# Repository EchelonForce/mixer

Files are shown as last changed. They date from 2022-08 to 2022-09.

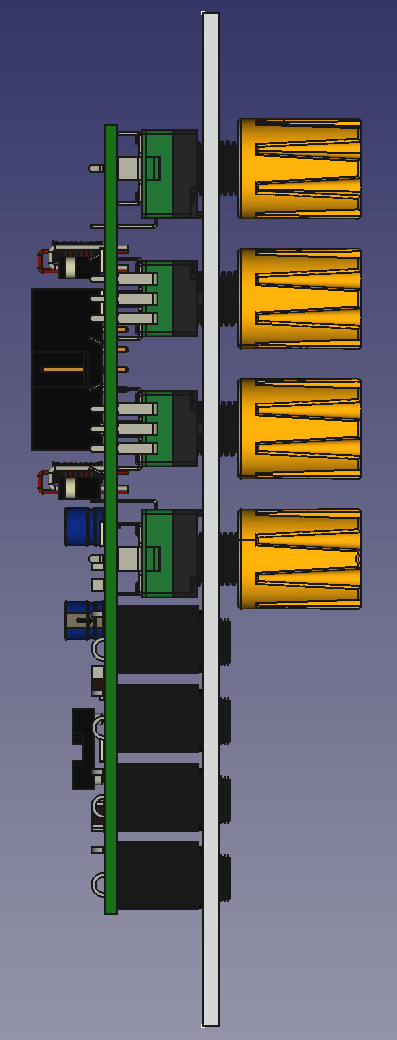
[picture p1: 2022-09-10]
front_panel_v1/render3.png

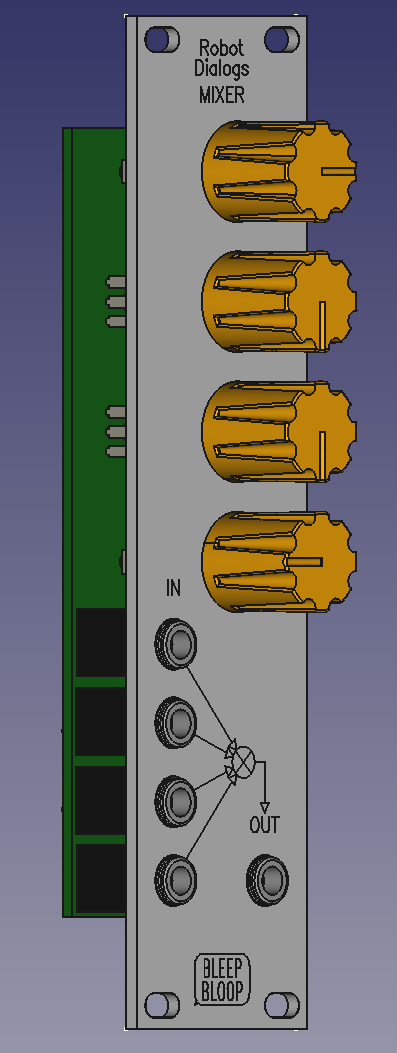
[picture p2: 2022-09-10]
front_panel_v1/render2.png

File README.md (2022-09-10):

# Eurorack Mixer Module

This the KiCAD design of a Eurorack mixer module with 4 inputs.

Full writeup here: https://www.robotdialogs.com/2022/09/eurorack-41-mixer-module.html

This work is licensed under a Creative Commons Attribution-NonCommercial-ShareAlike 4.0 International License. https://creativecommons.org/licenses/by-nc-sa/4.0/

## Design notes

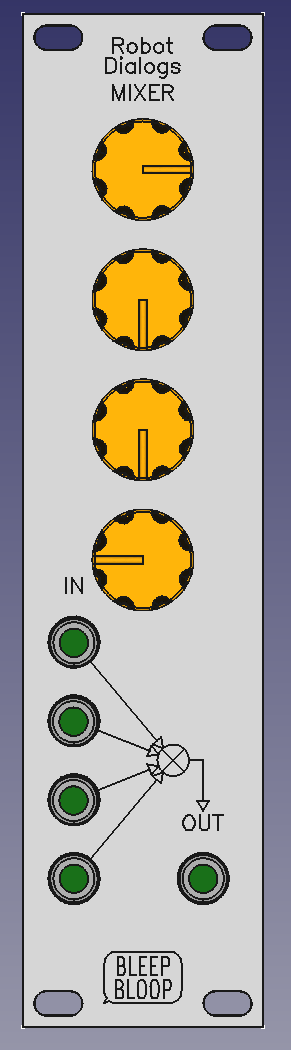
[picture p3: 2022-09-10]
front_panel_v1/render1.png

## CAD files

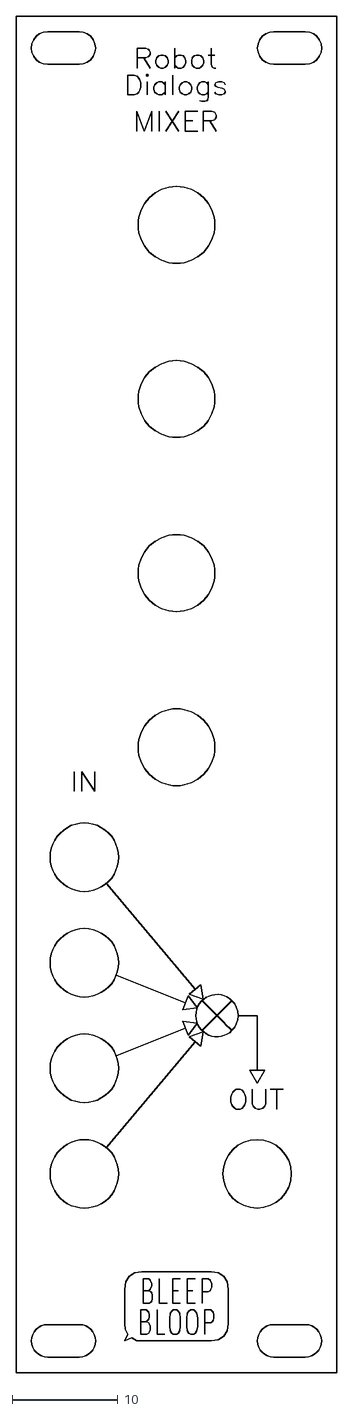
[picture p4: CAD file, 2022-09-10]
front_panel_v1/mixer_front_panel_v1_engraving.dxf
30.4 x 128.4

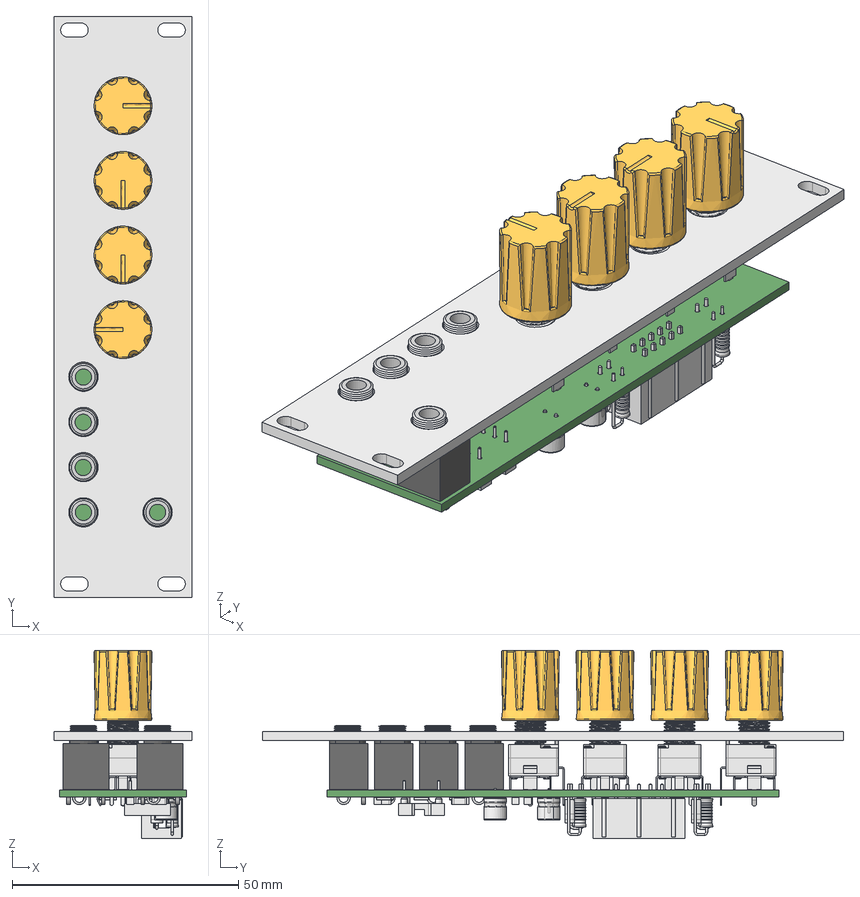
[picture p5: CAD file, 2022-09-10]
front_panel_v1/mixer_front_panel_v1.FCStd
30.5 x 128.5 x 41.6 mm
_autosave-mixer_v1 PCB

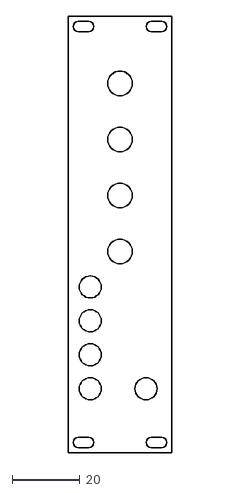
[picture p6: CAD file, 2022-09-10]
front_panel_v1/mixer_front_panel_v1_no_engraving.dxf
30.5 x 128.5

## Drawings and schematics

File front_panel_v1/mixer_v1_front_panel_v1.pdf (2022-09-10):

1

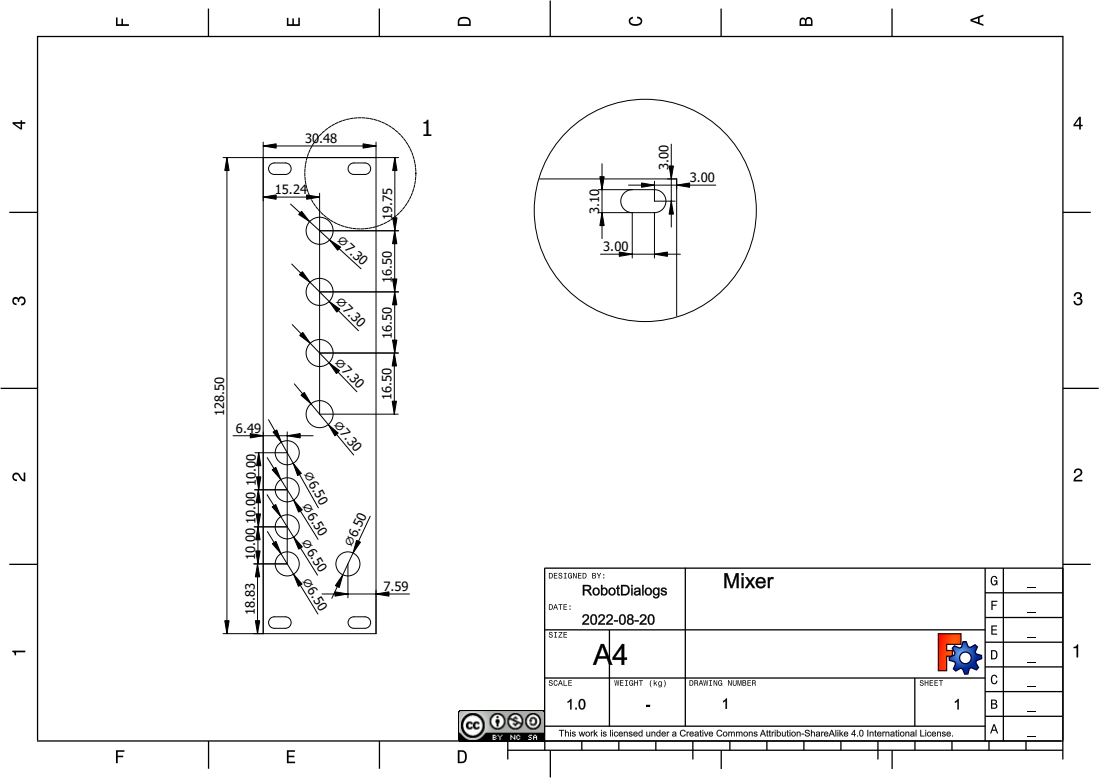
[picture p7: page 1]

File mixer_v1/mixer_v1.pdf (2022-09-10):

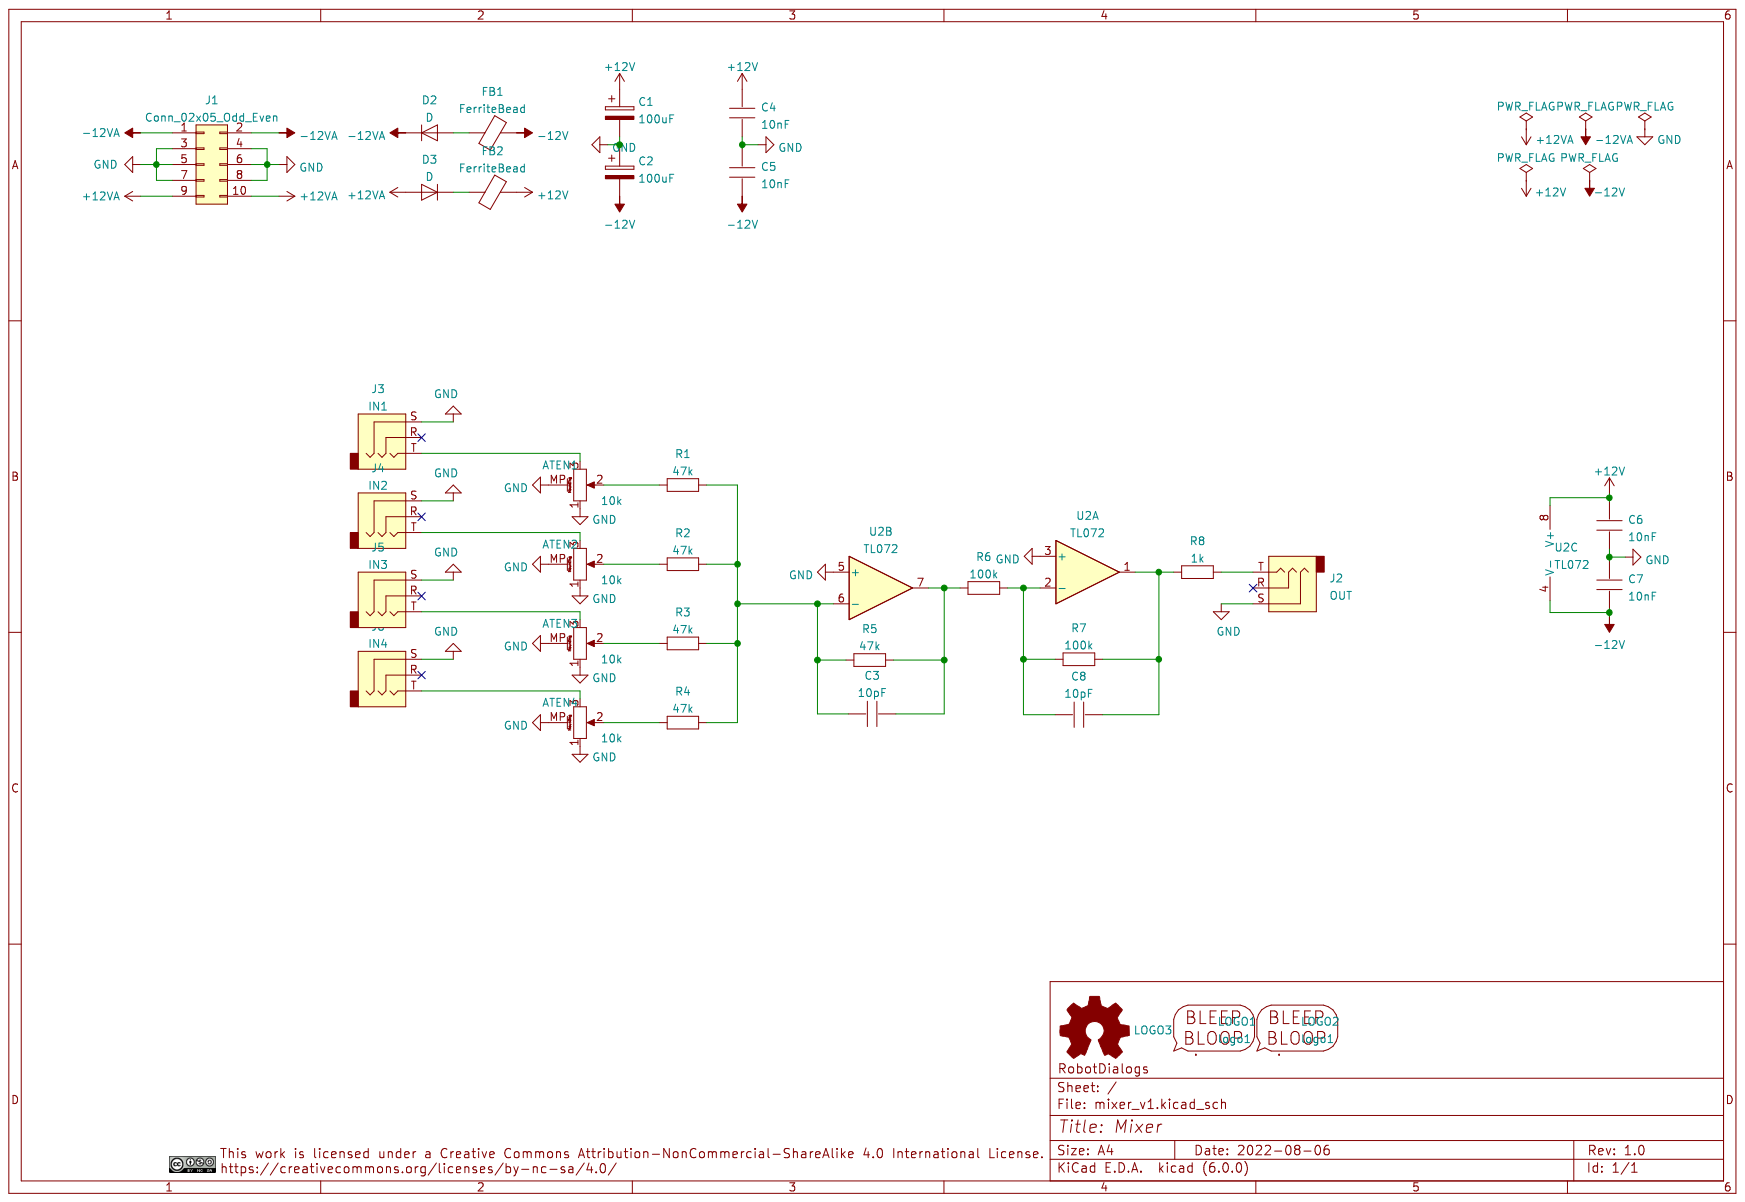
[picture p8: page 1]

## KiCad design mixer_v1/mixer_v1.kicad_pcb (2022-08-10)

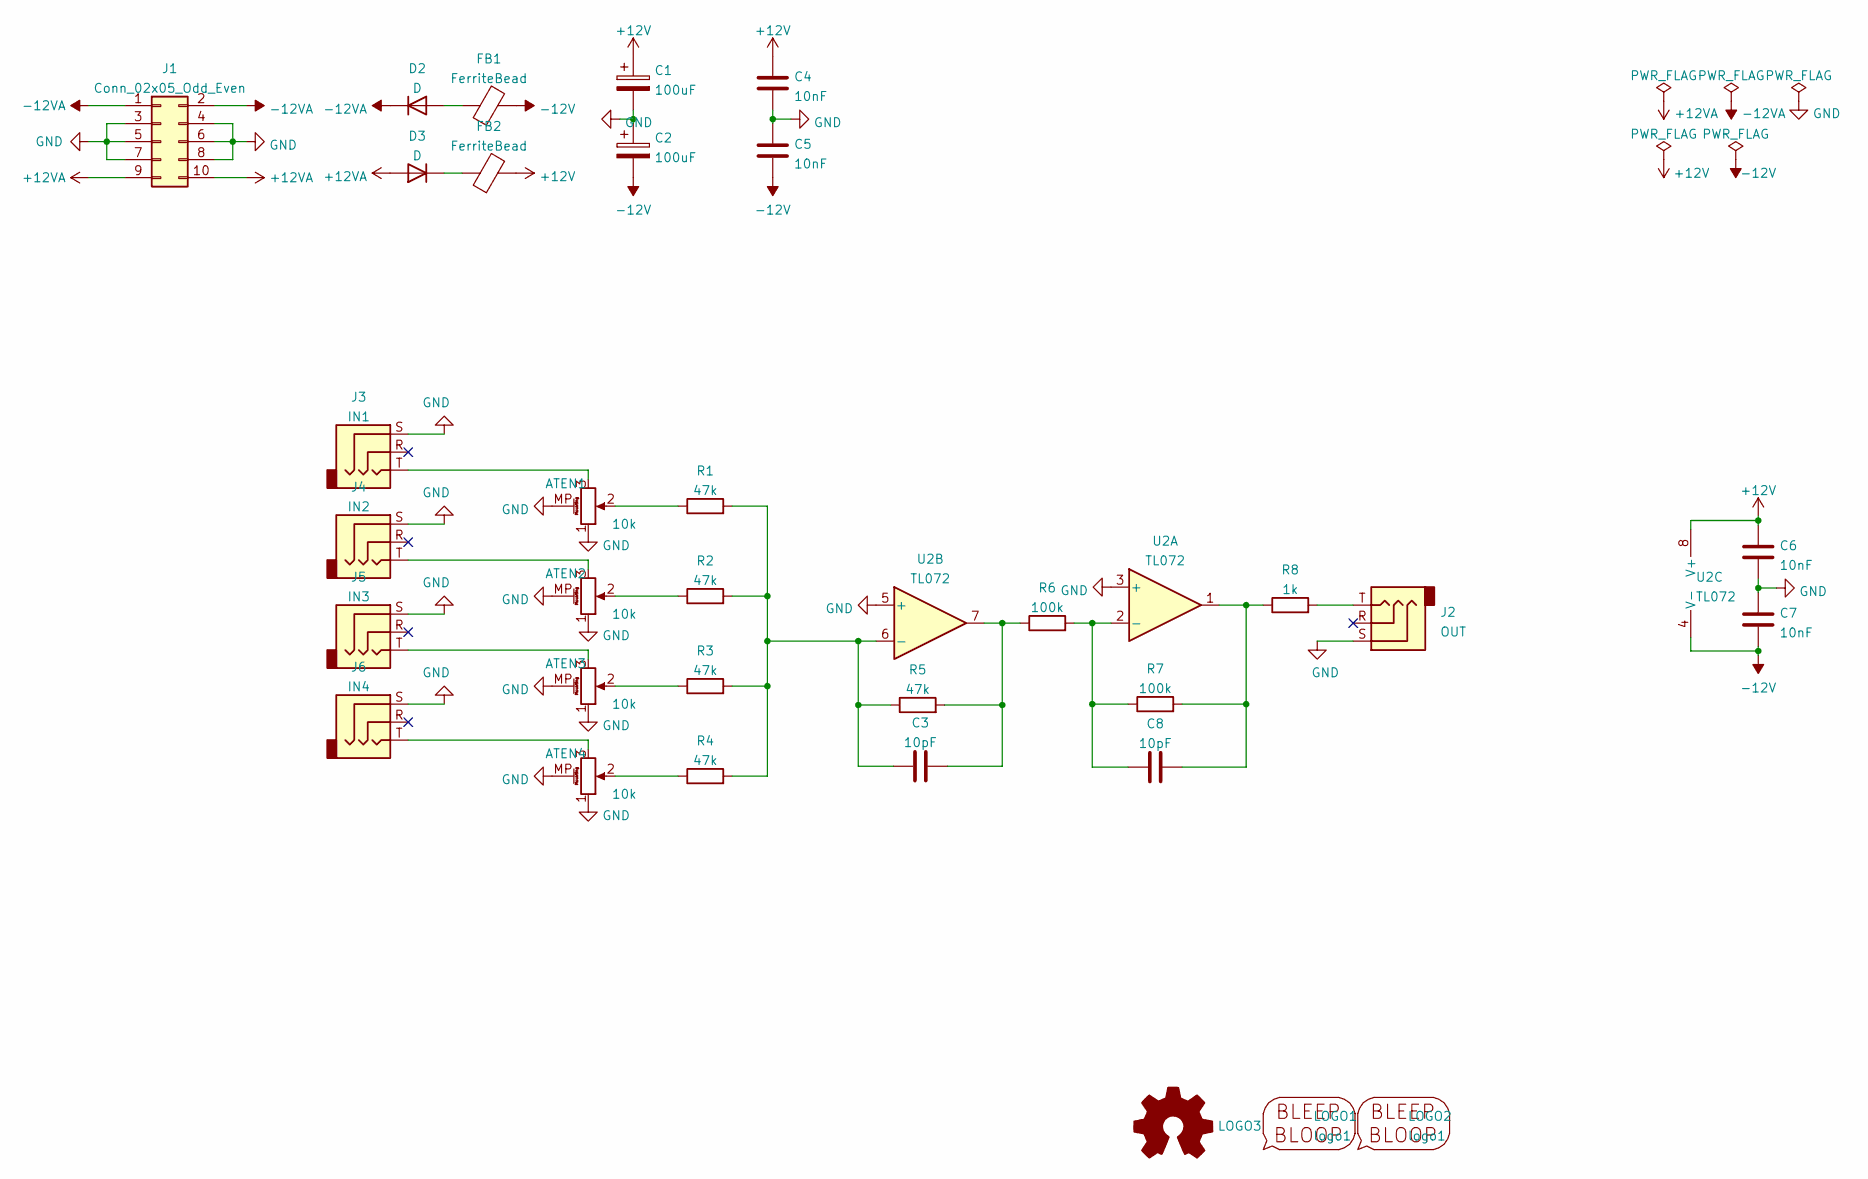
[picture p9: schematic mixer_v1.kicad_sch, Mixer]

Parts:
ATEN1, ATEN2, ATEN3, ATEN4: 10k; Potentiometer_Alpha_RD901F-40-00D_Single_Vertical_w_3d
C1, C2: 100uF; CP_Radial_D5.0mm_P2.50mm
C3, C8: 10pF; C_1206_3216Metric_Pad1.33x1.80mm_HandSolder
C4, C5, C6, C7: 10nF; C_1206_3216Metric_Pad1.33x1.80mm_HandSolder
D2, D3: D; D_A-405_P2.54mm_Vertical_KathodeUp
FB1, FB2: FerriteBead; L_Axial_L6.6mm_D2.7mm_P2.54mm_Vertical_Vishay_IM-2
J1: Conn_02x05_Odd_Even; IDC-Header_2x05_P2.54mm_Vertical
J2: OUT; Jack_3.5mm_MJ-355W_Vertical
J3: IN1; Jack_3.5mm_MJ-355W_Vertical
J4: IN2; Jack_3.5mm_MJ-355W_Vertical
J5: IN3; Jack_3.5mm_MJ-355W_Vertical
J6: IN4; Jack_3.5mm_MJ-355W_Vertical
LOGO1: logo1; Logo1
LOGO2: logo1; Logo2
LOGO3: Logo_Open_Hardware_Small; OSHW-Symbol_6.7x6mm_SilkScreen
R1, R2, R3, R4, R5: 47k; R_1206_3216Metric_Pad1.30x1.75mm_HandSolder
R6, R7: 100k; R_1206_3216Metric_Pad1.30x1.75mm_HandSolder
R8: 1k; R_1206_3216Metric_Pad1.30x1.75mm_HandSolder
U2: TL072; DIP-8_W7.62mm_Socket_LongPads

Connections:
+12V: C1.1, C4.1, C6.1, FB2.2, U2.8 (V+)
+12VA: D3.2 (A), J1.9, J1.10
-12V: C2.2, C5.2, C7.2, FB1.2, U2.4 (V-)
-12VA: D2.1 (K), J1.1, J1.2
GND: ATEN1.1, ATEN1.MP (MountPin), ATEN2.1, ATEN2.MP (MountPin), ATEN3.1, ATEN3.MP (MountPin), ATEN4.1, ATEN4.MP (MountPin), C1.2, C2.1, C4.2, C5.1, C6.2, C7.1, J1.3, J1.4, J1.5, J1.6, J1.7, J1.8, J2.S, J3.S, J4.S, J5.S, J6.S, U2.3 (+), U2.5 (+)
unnamed: ATEN1.2, R1.1
unnamed: ATEN1.3, J3.T
unnamed: ATEN2.2, R2.1
unnamed: ATEN3.2, R3.1
unnamed: ATEN3.3, J5.T
unnamed: ATEN4.2, R4.1
unnamed: ATEN4.3, J6.T
unnamed: D2.2 (A), FB1.1
unnamed: D3.1 (K), FB2.1
unnamed: J2.T, R8.2
unnamed: ATEN2.3, J4.T
unnamed: C8.2, R7.2, R8.1, U2.1
unnamed: C8.1, R6.2, R7.1, U2.2 (-)
unnamed: C3.1, R1.2, R2.2, R3.2, R4.2, R5.1, U2.6 (-)
unnamed: C3.2, R5.2, R6.1, U2.7

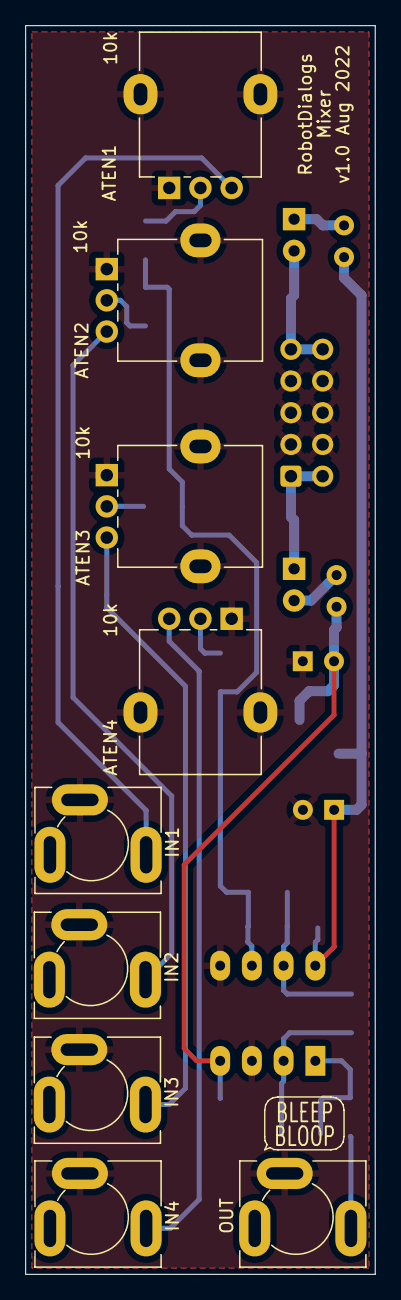
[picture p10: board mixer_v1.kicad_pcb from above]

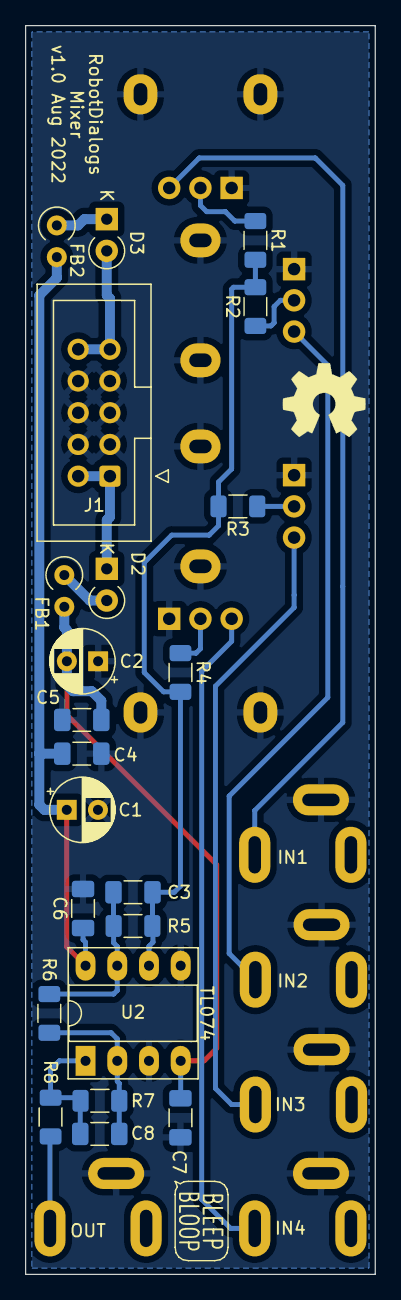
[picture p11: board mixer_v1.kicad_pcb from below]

Board: 2 copper layers, 28.0 x 100.0 mm, 34 parts (23 on the bottom side), 20 nets.

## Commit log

2022-08-10 Schematic and PCB v1.0
    [mixer_v1.kicad_pcb, mixer_v1.kicad_sch]
2022-09-10 Panelized v1 version for production
    [mixer_v1_panelized.kicad_pcb]
2022-09-10 Front Panel design files
    [mixer_front_panel_v1.FCStd, mixer_front_panel_v1_engraving.dxf, mixer_front_panel_v1_no_engraving.dxf]
